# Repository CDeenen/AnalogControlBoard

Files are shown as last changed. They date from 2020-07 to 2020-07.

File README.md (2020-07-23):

# AnalogControlBoard
The analog control board (ACB) is a complete solution for all your analog and digital input and output needs. The board has 8 16-bit analog output ports, 16 16-bit analog input ports and 32 digital GPIOs (general purpose inputs/outputs). The board is controlled with a NXP LPC1768 microcontroller that can be communicated with through the USB port.

More info can be found in the wiki: https://github.com/CDeenen/AnalogControlBoard/wiki

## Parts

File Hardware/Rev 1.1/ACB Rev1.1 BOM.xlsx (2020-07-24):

Column2 | Reference(s) | Value | Footprint | Specific | Article Nr
11 | C1, C2, C10, C15, C31, C32, C33, C34, C36, C38, C40 | 10uF | SMD 0603
5 | C3, C27, C28, C29, C39 | 1uF | SMD 0603
3 | C4, C19, C22 | 10nF | SMD 0603
1 | C5 | 100pF | SMD 0603
21 | C6, C7, C8, C9, C11, C12, C13, C14, C16, C20, C21, C25, C26, C30, C41, C42, C43, C44, C45, C46, C48 | 100nF | SMD 0603
1 | C17 | 10uF Tantalum | SMD 1206
1 | C18 | 22uF Tantalum | SMD 1206
1 | C23 | 100uF | SMD 6.3x7.7
2 | C24, C47 | 18pF | SMD 0603
1 | C35 | 10uF Low ESR, X5R | SMD 0603
1 | C37 | 100nF, X8R | SMD 0603
1 | R1 | 90.9K | SMD 0603
5 | R2, R3, R9, R11, R12 | 10K | SMD 0603
1 | R4 | 100K | SMD 0603
1 | R5 | 76.8K | SMD 0603
1 | R6 | 24.9K | SMD 0603
3 | R7, R8, R10 | 220R | SMD 0603
3 | D1, D2, D3 | LED | SMD 0603
14 | J1, J5, J6, J7, J8, J9, J10, J11, J12, J13, J14, J15, J16, J23 | 1x2 Pin Header | 1x2 Pin Header
2 | J2, J22 | 2x10 Pin Header | 2x10 Pin Header
1 | J17 | 2x3 Pin Header | 2x3 Pin Header
2 | J18, J20 | 1x4 Pin Header | 1x4 Pin Header
1 | J3 | USB_OTG | MicroUSB_B | HRS | ZX62D-B-5P8(30)
20 | P1, P3, P6, P7, P8, P9, P10, P11, P12, P13, P14, P15, P20, P21, P22, P23, P24, P25, P26, P27 | MMCX Connector | MMCXconnector - Edge Mount | Molex | 73415-0961
1 | SW1 | Switch | Switch | C&K | KMR231GLFS
1 | U1 | LPC1768 | LQFP-100_14x14mm_Pitch0.5mm | NPX | LPC1768FBD100
1 | U2 | TPS7A39 | WSON-10_3x3mm_Pitch0.5mm_ThermalVias | Texas Instruments | TPS7A3901DSCT
1 | U3 | TPS73201-EP | SOT-23-5 | Texas Instruments | TPS73201MDBVREP
1 | U4 | FT232RL | SSOP-28_5.3x10.2mm_Pitch0.65mm | FTDI | FT232RL
1 | U5 | LTC2666 | QFN-32-1EP_5x5mm_Pitch0.5mm | Analog Devices | LTC2666HUH-16
1 | U6 | LM1117-3.3 | SOT-223-3_TabPin2 | Texas Instruments | LM1117IMPX-3.3/NOPB
1 | U7 | AD7616 | LQFP-80_14x14mm_Pitch0.65mm | Analog Devices | AD7616BSTZ
1 | U9 | AT25_EEPROM | SOIC-8_3.9x4.9mm_Pitch1.27mm | Microchip | AT25320B-SSHL-B
1 | Y1 | 12MHz Crystal | SMD_3225-4pin_3.2x2.5mm | Abracon | ASE-12.000MHZ-LC-T
1 | Y2 | 32.768KHz RTC Crystal | SMD_3215-2pin_3.2x1.5mm | Epson | Q13FC13500005 FC-135 32.768KHZ 12.5PF
1 | External PSU |  |  | Cosel | LDC30F-2-SNY
12 | Jumpers

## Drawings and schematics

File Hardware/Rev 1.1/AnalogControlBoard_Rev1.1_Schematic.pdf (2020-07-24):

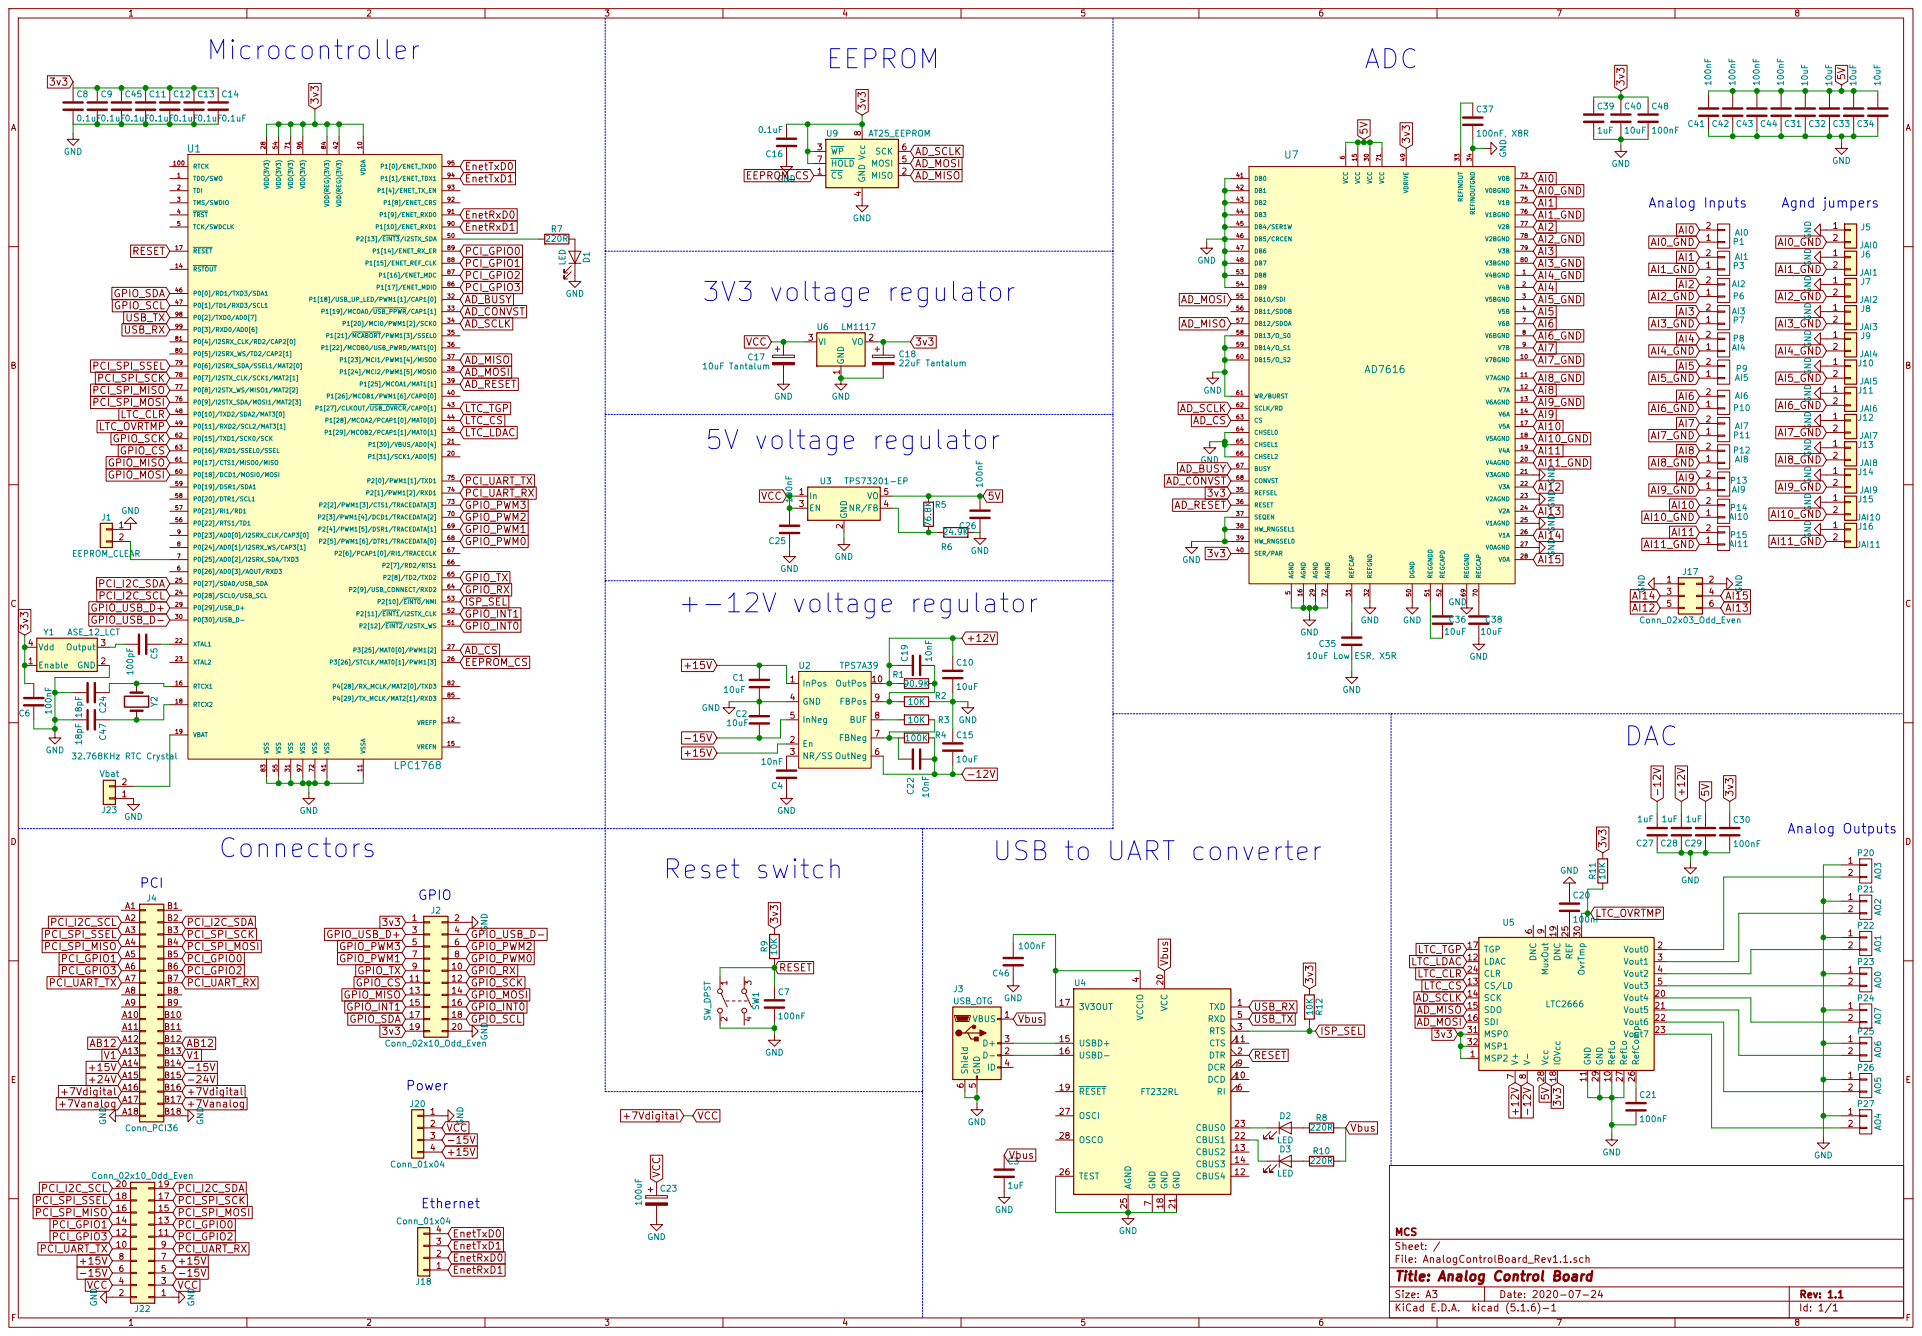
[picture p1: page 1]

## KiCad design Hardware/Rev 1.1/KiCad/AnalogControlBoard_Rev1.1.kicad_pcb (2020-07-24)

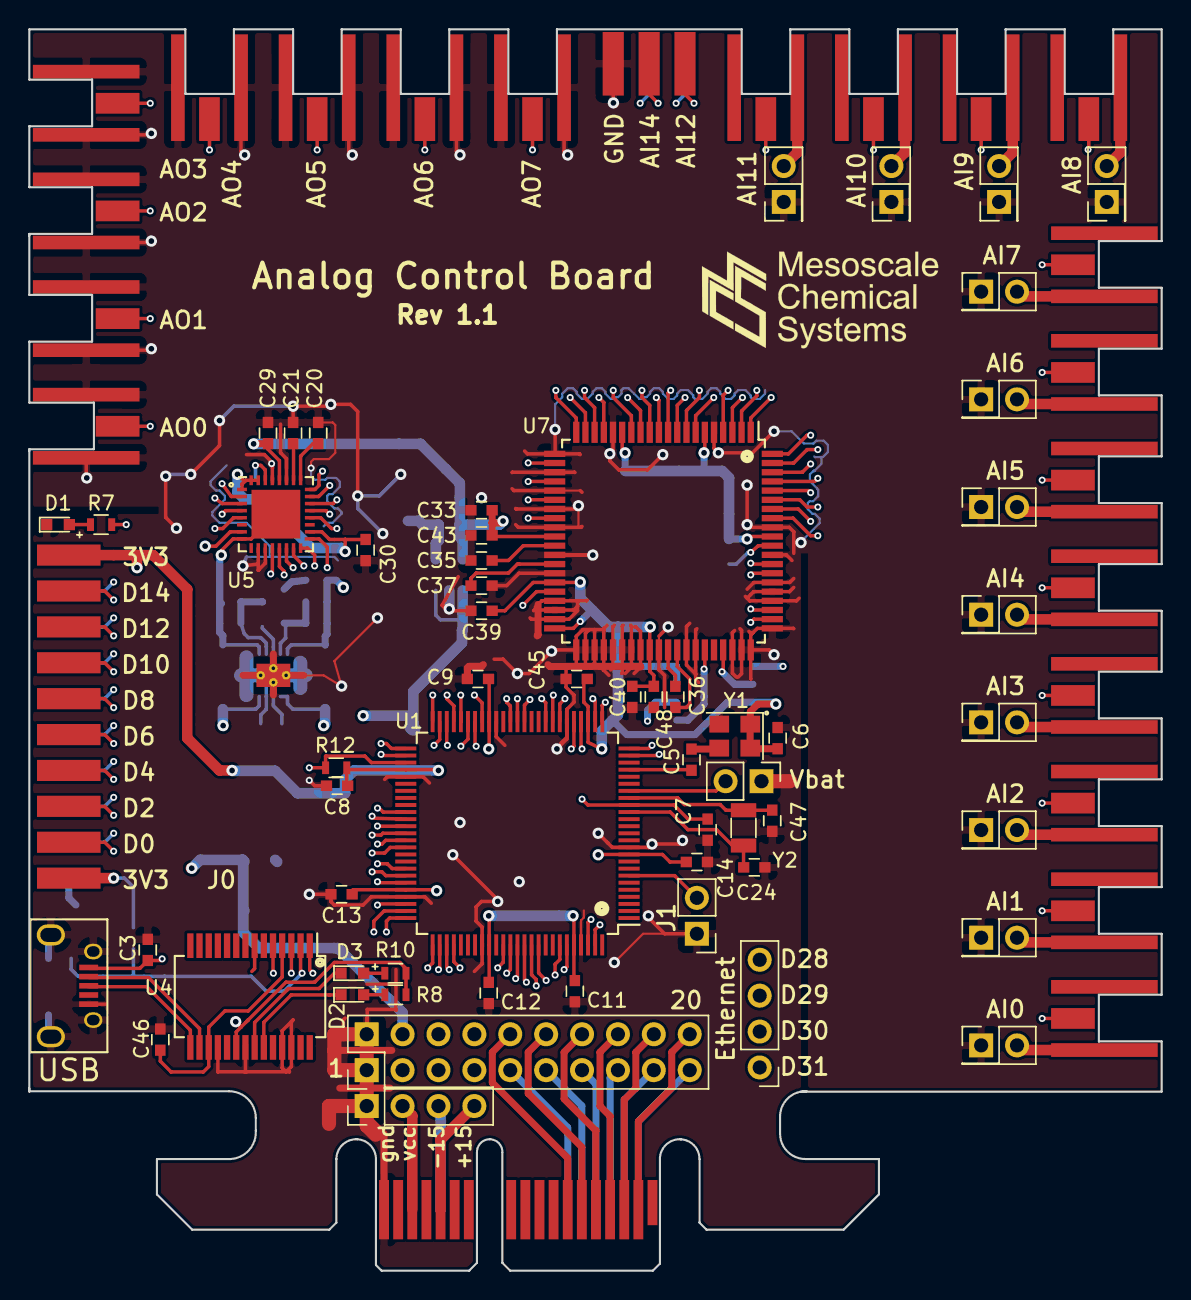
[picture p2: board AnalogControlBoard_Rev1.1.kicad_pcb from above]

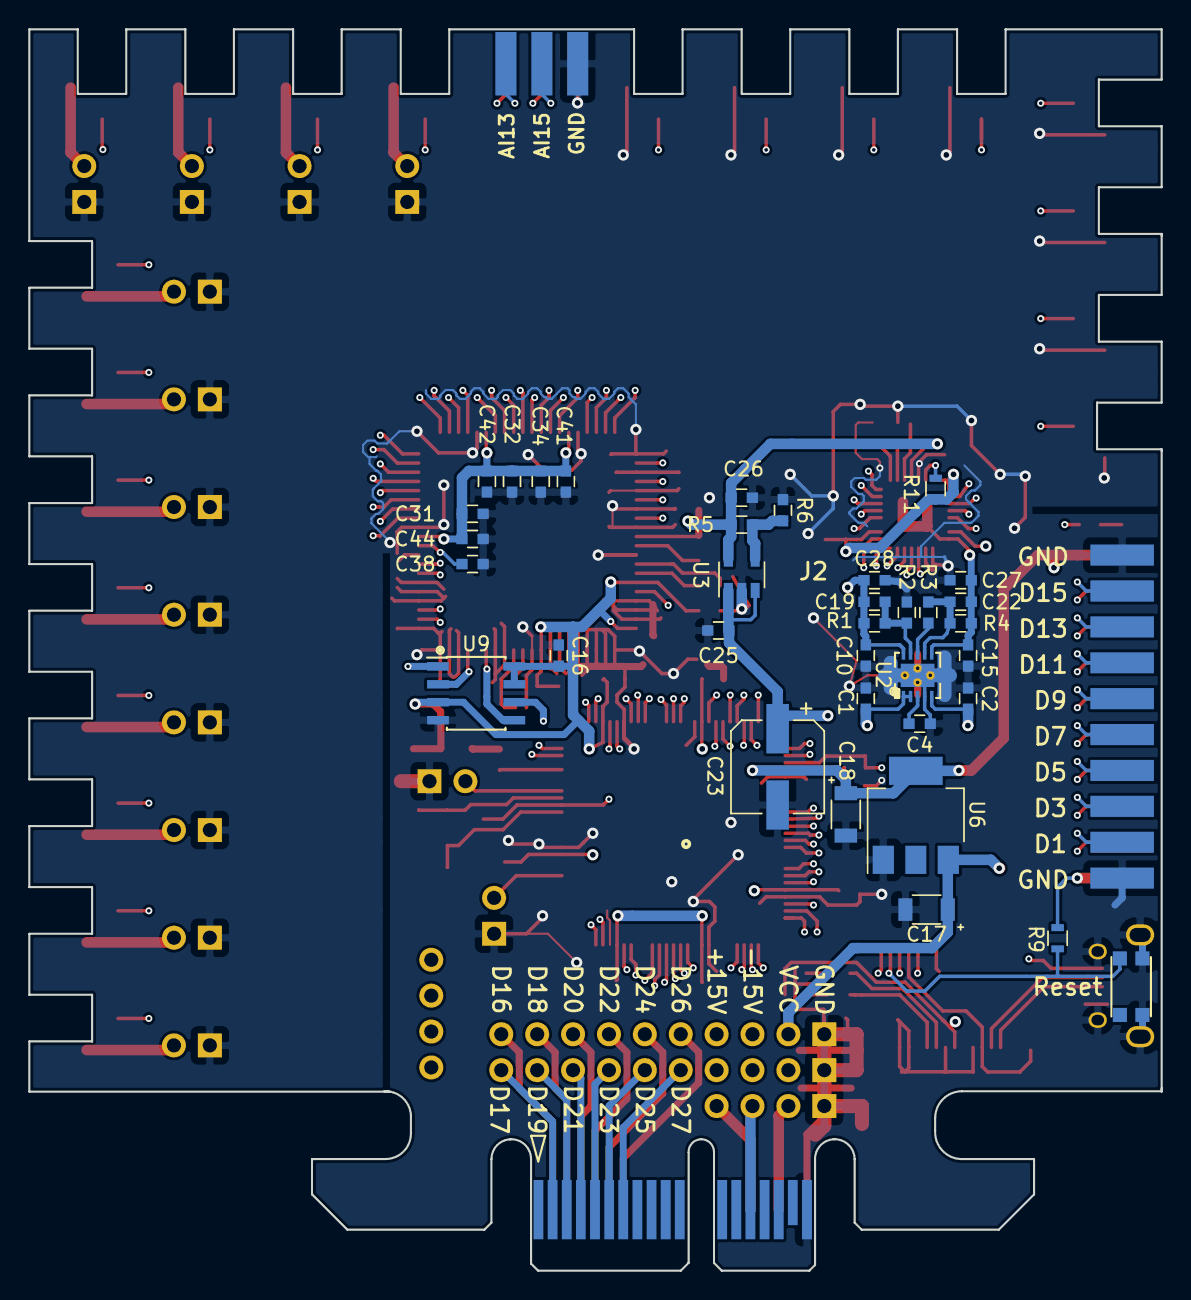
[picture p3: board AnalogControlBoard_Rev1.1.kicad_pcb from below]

Board: 4 copper layers, 80.1 x 87.9 mm, 115 parts (36 on the bottom side), 123 nets.

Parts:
C1, C2, C10, C15, C31, C32, C33, C34, C36, C38, C40: 10uF; C_0603
C3, C27, C28, C29, C39: 1uF; C_0603
C4, C19, C22: 10nF; C_0603
C5: 100pF; C_0603
C6, C7, C20, C21, C25, C26, C30, C41, C42, C43, C44, C46: 100nF; C_0603
C8, C9, C11, C12, C13, C14, C16, C45: 0.1uF; C_0603
C17: 10uF Tantalum; C_1206
C18: 22uF Tantalum; C_1206
C23: 100uF; CP_Elec_6.3x7.7
C24, C47: 18pF; C_0603
C35: 10uF Low ESR, X5R; C_0603
C37: 100nF, X8R; C_0603
C48: 100nF; Capacitor_0603
D1, D2, D3: LED; LED_0603
J1: EEPROM_CLEAR; Pin_Header_Straight_1x02_Pitch2.54mm
J2: Conn_02x10_Odd_Even; 2x10pinSideMount
J3: USB_OTG; MicroUSB_B
J4: Conn_PCI36; PCI-36
J5: JAI0; Pin_Header_Straight_2x01_Pitch2.54mm
J6: JAI1; Pin_Header_Straight_2x01_Pitch2.54mm
J7: JAI2; Pin_Header_Straight_2x01_Pitch2.54mm
J8: JAI3; Pin_Header_Straight_2x01_Pitch2.54mm
J9: JAI4; Pin_Header_Straight_2x01_Pitch2.54mm
J10: JAI5; Pin_Header_Straight_2x01_Pitch2.54mm
J11: JAI6; Pin_Header_Straight_2x01_Pitch2.54mm
J12: JAI7; Pin_Header_Straight_2x01_Pitch2.54mm
J13: JAI8; Pin_Header_Straight_2x01_Pitch2.54mm
J14: JAI9; Pin_Header_Straight_2x01_Pitch2.54mm
J15: JAI10; Pin_Header_Straight_2x01_Pitch2.54mm
J16: JAI11; Pin_Header_Straight_2x01_Pitch2.54mm
J17: Conn_02x03_Odd_Even; 2x3pinSideMount
J18, J20: Conn_01x04; Pin_Header_Straight_1x04_Pitch2.54mm
J22: Conn_02x10_Odd_Even; Pin_Header_Straight_2x10_Pitch2.54mm
J23: Vbat; Pin_Header_Straight_1x02_Pitch2.54mm
P1: AI0; MMCXconnector
P3: AI1; MMCXconnector
P6: AI2; MMCXconnector
P7: AI3; MMCXconnector
P8: AI4; MMCXconnector
P9: AI5; MMCXconnector
P10: AI6; MMCXconnector
P11: AI7; MMCXconnector
P12: AI8; MMCXconnector
P13: AI9; MMCXconnector
P14: AI10; MMCXconnector
P15: AI11; MMCXconnector
P20: AO3; MMCXconnector
P21: AO2; MMCXconnector
P22: AO1; MMCXconnector
P23: AO0; MMCXconnector
P24: AO7; MMCXconnector
P25: AO6; MMCXconnector
P26: AO5; MMCXconnector
P27: AO4; MMCXconnector
R1: 90.9K; C_0603
R2, R3: 10K; C_0603
R4: 100K; C_0603
R5: 76.8K; C_0603
R6: 24.9K; C_0603
R7, R8, R10: 220R; R_0603
R9, R11, R12: 10K; R_0603
SW1: SW_DPST; Switch
U1: LPC1768; LQFP-100_14x14mm_Pitch0.5mm
U2: TPS7A39; WSON-10_3x3mm_Pitch0.5mm_ThermalVias
U3: TPS73201-EP; SOT-23-5
U4: FT232RL; SSOP-28_5.3x10.2mm_Pitch0.65mm
U5: LTC2666; QFN-32-1EP_5x5mm_Pitch0.5mm
U6: LM1117; SOT-223-3_TabPin2
U7: AD7616; LQFP-80_14x14mm_Pitch0.65mm
U9: AT25_EEPROM; SOIC-8_3.9x4.9mm_Pitch1.27mm
Y1: ASE_12_LCT; Crystal_SMD_3225-4pin_3.2x2.5mm
Y2: 32.768KHz RTC Crystal; Crystal_SMD_3215-2pin_3.2x1.5mm

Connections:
3v3: C6.2, C8.1, C9.1, C11.1, C12.1, C13.1, C14.1, C16.2, C18.1, C30.1, C39.1, C40.1, C45.1, C48.1, J2.1, J2.19, R9.2, R11.2, R12.1, U1.10, U1.28, U1.42, U1.54, U1.71, U1.84, U1.96, U5.1, U5.18, U5.31, U5.32, U6.2, U7.35, U7.40, U7.49, U9.3, U9.7, U9.8, Y1.1, Y1.4
5V: C26.2, C29.2, C31.2, C32.2, C33.2, C34.2, C41.2, C42.2, C43.2, C44.2, R5.2, U3.5, U5.28, U7.6, U7.15, U7.30, U7.71
+7Vanalog: J4.A17, J4.B17
+7Vdigital: C17.1, C23.1, C25.2, J4.A16, J4.B16, J20.2, J22.3, J22.4, U3.1, U3.3, U6.3
+12V: C10.1, C19.1, C28.2, R1.2, U2.10, U5.7
+15V: C1.1, J4.A14, J20.4, J22.7, J22.8, U2.1, U2.2
-12V: C15.2, C22.2, C27.2, R4.1, U2.6, U5.8
-15V: C2.2, J4.B14, J20.3, J22.5, J22.6, U2.5
AB12: J4.A12, J4.B12
AD_BUSY: U1.32, U7.67
AD_CONVST: U1.33, U7.68
AD_CS: U1.27, U7.63
AD_MISO: U1.37, U5.15, U7.57, U9.2
AD_MOSI: U1.38, U5.16, U7.55, U9.5
AD_RESET: U1.39, U7.36
AD_SCLK: U1.34, U5.14, U7.62, U9.6
AI0: P1.2, U7.73
AI0_GND: J5.2, P1.1, U7.74
AI1: P3.2, U7.75
AI1_GND: J6.2, P3.1, U7.76
AI2: P6.2, U7.77
AI2_GND: J7.2, P6.1, U7.78
AI3: P7.2, U7.79
AI3_GND: J8.2, P7.1, U7.80
AI4: P8.2, U7.2
AI4_GND: J9.2, P8.1, U7.1
AI5: P9.2, U7.4
AI5_GND: J10.2, P9.1, U7.3
AI6: P10.2, U7.7
AI6_GND: J11.2, P10.1, U7.8
AI7: P11.2, U7.9
AI7_GND: J12.2, P11.1, U7.10
AI8_GND: J13.2, P12.1, U7.11
AI9: P13.2, U7.14
AI9_GND: J14.2, P13.1, U7.13
AI10: P14.2, U7.17
AI10_GND: J15.2, P14.1, U7.18
AI11: P15.2, U7.19
AI11_GND: J16.2, P15.1, U7.20
AI12: J17.5, U7.22
AI13: J17.6, U7.24
AI14: J17.3, U7.26
AI15: J17.4, U7.28
EEPROM_CS: U1.26, U9.1
EnetRxD0: J18.2, U1.91
EnetRxD1: J18.1, U1.90
EnetTxD0: J18.4, U1.95
EnetTxD1: J18.3, U1.94
GND: C1.2, C2.1, C3.2, C4.1, C6.1, C7.2, C8.2, C9.2, C10.2, C11.2, C12.2, C13.2, C14.2, C15.1, C16.1, C17.2, C18.2, C20.1, C21.2, C23.2, C24.2, C25.1, C26.1, C27.1, C28.1, C29.1, C30.2, C31.1, C32.1, C33.1, C34.1, C35.1, C37.2, C38.1, C39.2, C40.2, C41.1, C42.1, C43.1, C44.1, C45.2, C46.1, C47.2, C48.2, D1.1, J1.1, J2.2, J2.20, J3.5, J3.6, J4.A18, J4.B18, J5.1, J6.1, J7.1, J8.1, J9.1, J10.1, J11.1, J12.1, J13.1, J14.1, J15.1, J16.1, J17.1, J17.2, J20.1, J22.1, J22.2, J23.1, P20.1, P21.1, P22.1, P23.1, P24.1, P25.1, P26.1, P27.1, R2.1, R6.2, SW1.2, U1.11, U1.31, U1.41, U1.55, U1.72, U1.83, U1.97, U2.4, U3.2, U4.21, U4.25, U4.26, U5.10, U5.11, U5.27, U5.29, U6.1, U7.5, U7.16, U7.21, U7.23, U7.25, U7.27, U7.29, U7.32, U7.34, U7.37, U7.38, U7.39, U7.41, U7.42, U7.43, U7.44, U7.45, U7.46, U7.47, U7.48, U7.50, U7.53, U7.54, U7.58, U7.59, U7.60, U7.61, U7.64, U7.65, U7.66, U7.69, U7.72, U9.4, Y1.2
GPIO_CS: J2.11, U1.63
GPIO_INT0: J2.16, U1.51
GPIO_INT1: J2.15, U1.52
GPIO_MISO: J2.13, U1.61
GPIO_MOSI: J2.14, U1.60
GPIO_PWM0: J2.8, U1.68
GPIO_PWM1: J2.7, U1.69
GPIO_PWM2: J2.6, U1.70
GPIO_PWM3: J2.5, U1.73
GPIO_RX: J2.10, U1.64
GPIO_SCK: J2.12, U1.62
GPIO_SCL: J2.18, U1.47
GPIO_SDA: J2.17, U1.46
GPIO_TX: J2.9, U1.65
GPIO_USB_D+: J2.3, U1.29
GPIO_USB_D-: J2.4, U1.30
ISP_SEL: R12.2, U1.53, U4.3
LTC_CLR: U1.48, U5.24
LTC_CS: U1.44, U5.13
LTC_LDAC: U1.45, U5.12
LTC_OVRTMP: R11.1, U1.49, U5.30
LTC_TGP: U1.43, U5.17
unnamed: C4.2, U2.3
unnamed: C5.1, U1.22
unnamed: C5.2, Y1.3
unnamed: C19.2, R1.1, R2.2, U2.9
unnamed: C20.2, U5.25
unnamed: C21.1, U5.26
unnamed: C22.1, R3.1, R4.2, U2.7
unnamed: C24.1, U1.16, Y2.1
unnamed: C35.2, U7.31
unnamed: C36.1, U7.51
unnamed: C36.2, U7.52
unnamed: C37.1, U7.33
unnamed: C38.2, U7.70
unnamed: C46.2, U4.4, U4.17
unnamed: C47.1, U1.18, Y2.2
unnamed: D1.2, R7.1
unnamed: D2.1, U4.23
unnamed: D2.2, R8.1
unnamed: D3.1, U4.22
unnamed: D3.2, R10.1
unnamed: J1.2, U1.7
unnamed: J3.2, U4.16
unnamed: J3.3, U4.15
unnamed: J23.2, U1.19
unnamed: P20.2, U5.2
unnamed: P21.2, U5.3
unnamed: P22.2, U5.4
unnamed: P23.2, U5.5
unnamed: P24.2, U5.20
unnamed: P25.2, U5.21
unnamed: P26.2, U5.22
unnamed: P27.2, U5.23
unnamed: R3.2, U2.8
unnamed: R5.1, R6.1, U3.4
unnamed: R7.2, U1.50
PCI_GPIO0: J4.B5, J22.13, U1.89
PCI_GPIO1: J4.A5, J22.14, U1.88
PCI_GPIO2: J4.B6, J22.11, U1.87
PCI_GPIO3: J4.A6, J22.12, U1.86
PCI_I2C_SCL: J4.A2, J22.20, U1.24
PCI_I2C_SDA: J4.B2, J22.19, U1.25
PCI_SPI_MISO: J4.A4, J22.16, U1.77
PCI_SPI_MOSI: J4.B4, J22.15, U1.76
PCI_SPI_SCK: J4.B3, J22.17, U1.78
PCI_SPI_SSEL: J4.A3, J22.18, U1.79
PCI_UART_RX: J4.B7, J22.9, U1.74
PCI_UART_TX: J4.A7, J22.10, U1.75
RESET: C7.1, R9.1, SW1.1, U1.17, U4.2
USB_RX: U1.99, U4.1
USB_TX: U1.98, U4.5
V1: J4.A13, J4.B13
Vbus: C3.1, J3.1, R8.2, R10.2, U4.20
